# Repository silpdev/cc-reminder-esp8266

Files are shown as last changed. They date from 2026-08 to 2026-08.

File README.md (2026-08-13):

# cc-reminder-esp8266

Đèn báo trạng thái Claude Code, chạy trên Wemos D1 Mini (ESP8266) + WS2812.
Kèm vỏ in 3D tham số hoá.

Port từ [Curlyfuu/cc_reminder](https://github.com/Curlyfuu/cc_reminder) — bản
gốc dùng ESP32-C3 + BLE. ESP8266 không có Bluetooth nên bản này chuyển sang
WiFi/HTTP, và hoá ra lại nhanh hơn: mỗi hook mất ~50ms thay vì 1–3 giây scan BLE.
Đổi lại, đèn cắm nguồn USB ở đâu cũng được, không cần ở gần máy tính.

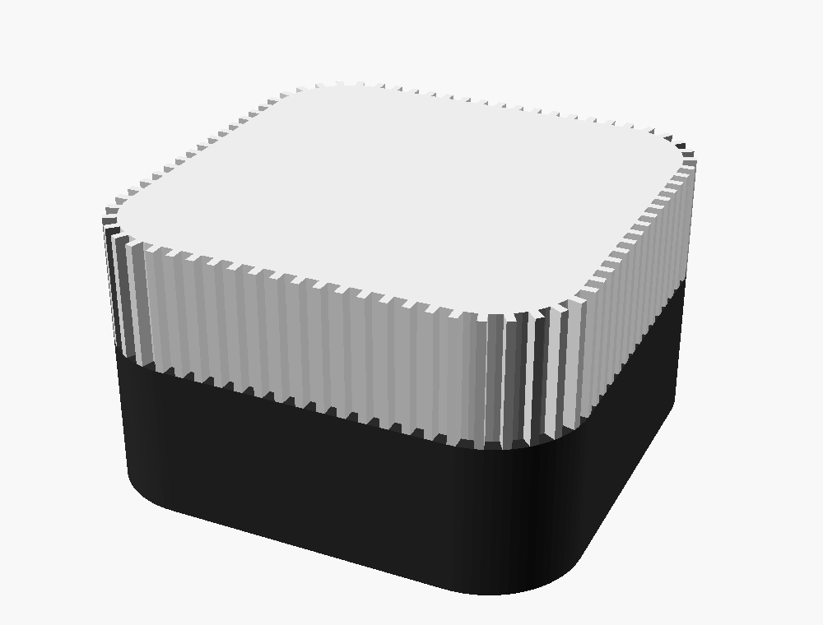
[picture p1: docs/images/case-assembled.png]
Vỏ lắp hoàn chỉnh


| Màu | Trạng thái | Khi nào |
|---|---|---|
| Xanh lá, sáng đứng | `IDLE` | Claude Code rảnh |
| Vàng cam, đập chậm | `WORKING` | đang chạy |
| Đỏ, đập nhanh | `INTERACT` | đang xin xác nhận quyền |

## Phần cứng

| Món | Ghi chú |
|---|---|
| Wemos D1 Mini (ESP8266) | |
| 1 LED WS2812B | cắt ra từ dây strip |
| 3 sợi dây 26–28 AWG | dây nhiều sợi mảnh, đừng dùng dây đơn cứng |

### Đấu nối

| Strip | D1 Mini |
|---|---|
| VCC (5V) | **3V3** |
| DIN | **D9 / RX (GPIO3)** |
| GND | G |

Hai điểm dễ sai:

**GPIO3 là bắt buộc.** Thư viện `NeoPixelBus` chỉ chạy được DMA trên chân này.
Nếu dùng bit-bang (`Adafruit_NeoPixel`) thì WiFi interrupt sẽ cắt ngang làm sai
timing → LED nhảy màu ngẫu nhiên. Đây là lỗi kinh điển của combo
ESP8266 + WS2812 + WiFi.

**Cấp nguồn từ 3V3, không phải 5V.** Ngưỡng HIGH của WS2812 là 0.7 × Vdd. Ở
3.3V thì ngưỡng chỉ ~2.3V, khớp thoải mái với mức GPIO. Nếu cấp 5V thì ngưỡng
lên 3.5V, cao hơn mức GPIO xuất ra — chạy được nhưng không ổn định. Với 1 LED
thì 3V3 dư sức.

Nếu dùng nhiều LED và buộc phải cấp 5V: mắc 1 diode 1N4148 nối tiếp trên dây
nguồn, sụt 0.6V xuống ~4.4V để hạ ngưỡng về ~3.1V.

## Cài đặt

### 1. Test LED trước

```bash
cd test
pio run -t upload && pio device monitor
```

Phải thấy đỏ → xanh lá → xanh dương → trắng. Nếu đỏ và xanh lá đổi chỗ nhau,
sửa `NeoGrbFeature` thành `NeoRgbFeature`.

### 2. Nạp firmware

```bash
cd firmware
pio run -t upload
```

Không cần sửa code — WiFi cấu hình qua trang web, xem mục bên dưới.

Kiểm tra: `curl http://cc-reminder.local/api/status`

### 3. Cấu hình hook Claude Code

Chép `host/settings.example.json` vào `~/.claude/settings.json`, sửa đường dẫn.
Kiểm tra bằng `/hooks` trong Claude Code — menu đó liệt kê mọi hook đang có và
cho biết nó đến từ file settings nào.

| Event | Trạng thái | Tại sao chọn event này |
|---|---|---|
| `SessionStart` | IDLE | đặt lại đèn khi mở session |
| `UserPromptSubmit` | WORKING | bắn ngay khi bạn gửi prompt |
| `Notification` | INTERACT | matcher `permission_prompt\|idle_prompt\|agent_needs_input` |
| `Stop` | IDLE | Claude trả lời xong |
| `SessionEnd` | IDLE | đóng session |

**Vì sao `Notification` mà không phải `PermissionRequest`.** Cả hai đều có thật.
Nhưng `PermissionRequest` bắn mỗi khi có quyết định về quyền, kể cả những lần
được rule tự cho qua mà không hỏi bạn — đèn sẽ nháy đỏ vô ích.
`Notification` với matcher trên chỉ bắn khi Claude **thật sự đang chờ bạn**, và
bắt thêm cả trường hợp đứng chờ mà không phải xin quyền (`idle_prompt`), đúng
là lúc bạn cần đèn báo nhất. Muốn dùng `PermissionRequest` thì cũng được, thêm
song song vào cũng không sao.

**Mọi hook đều `async: true`.** Hook chạy nền, không chặn session. Nếu không có
cờ này, `UserPromptSubmit` sẽ chặn Claude xử lý prompt cho tới khi hook xong —
mà bước dò IP lần đầu có thể mất ~1 giây.

**Dùng exec form (`command` + `args`).** Mỗi phần tử `args` được truyền thành
đúng một tham số, không qua shell, nên đường dẫn có dấu cách cũng không sao.

### Vì sao script luôn exit 0

Đây không phải chi tiết nhỏ. Trong Claude Code, exit code 2 của hook có nghĩa
khác nhau tùy event, và với các event mình dùng thì rất tệ:

| Event | Exit 2 gây ra |
|---|---|
| `UserPromptSubmit` | **chặn prompt và xoá nó khỏi context** |
| `Stop` | **ngăn Claude dừng, bắt nó tiếp tục** |

Nghĩa là một cái đèn LED rút phích có thể làm treo phiên làm việc của bạn.
Script bắt mọi exception và luôn trả về 0, kể cả khi không tìm thấy thiết bị.

### Vì sao script không in ra stdout

Với `UserPromptSubmit`, Claude Code lấy stdout của hook làm **context cho
Claude đọc**. Nên script chỉ in khi bạn gọi tay (`STATUS`, `discover`); lúc đổi
trạng thái nó im lặng hoàn toàn. Muốn xem log thì đặt `CC_REMINDER_DEBUG=1`,
log đi ra stderr.

Tài liệu hook: https://code.claude.com/docs/en/hooks

## Trang web cấu hình

Firmware trong `firmware/` có trang web cấu hình, **không cần sửa code hay nạp
lại để đổi WiFi hoặc màu đèn**. Cấu hình lưu trong EEPROM.

### Lần đầu

1. Nạp firmware, cấp nguồn
2. Đèn **đập xanh dương** = đang ở chế độ AP, chờ cấu hình
3. Kết nối WiFi `cc-reminder-setup` (mở, không mật khẩu)
4. Mở `http://192.168.4.1` — điện thoại thường tự bung trang lên nhờ captive portal
5. Bấm **Quét**, điền tối đa 3 mạng WiFi, bấm **Lưu & khởi động lại**

Sau đó vào `http://cc-reminder.local` (hoặc IP) để cấu hình tiếp.

Nếu không mạng nào trong danh sách khả dụng, thiết bị quay về chế độ AP.

### Cấu hình được gì

| | Ghi chú |
|---|---|
| Độ sáng | 1–255, áp dụng ngay |
| Số LED | 1–24, cần khởi động lại |
| Thứ tự màu | GRB / RGB — sửa lỗi "đỏ ra xanh lá" ngay từ web, khỏi nạp lại |
| Màu từng trạng thái | color picker cho IDLE / WORKING / INTERACT |
| Nhịp đập | bật/tắt và chu kỳ riêng cho từng trạng thái |
| Ambient | thời gian chờ, hiệu ứng, tốc độ, độ sáng riêng, màu |
| 3 mạng WiFi | nhà / công ty / hotspot, cần khởi động lại |
| Hostname | cần khởi động lại |

Có sẵn 3 nút thử IDLE / WORKING / INTERACT để xem màu ngay trên đèn thật, và
nút xoá cấu hình về mặc định.

Mật khẩu WiFi **không bao giờ được gửi về trình duyệt**. Để trống ô mật khẩu
khi lưu thì mật khẩu cũ được giữ nguyên.

### Sửa trang web

HTML nằm ở `firmware/web/page.html`, được nhúng vào PROGMEM trong `main.cpp`.
Sau khi sửa HTML:

```bash
python3 tools/embed_page.py
```

Script chỉ thay phần giữa 2 marker `PAGE BEGIN` / `PAGE END`, không đụng vào
code còn lại. Đừng sửa HTML trực tiếp trong `main.cpp` — lần chạy script sau
sẽ ghi đè.

### API

| Endpoint | |
|---|---|
| `GET /` | trang cấu hình |
| `GET /state?s=IDLE\|WORKING\|INTERACT` | đổi trạng thái (dùng cho hook) |
| `GET /status` | tên trạng thái, dạng text |
| `GET /api/status` | JSON: state, ap, slot, ssid, ip, host, rssi, uptime, heap, fx, fxname, idlefor |
| UDP `:45678` gửi `CCR?` | trả về JSON có IP — dùng để dò thiết bị |
| `GET /api/config` | JSON cấu hình hiện tại (không có mật khẩu) |
| `POST /api/config` | lưu cấu hình, form-urlencoded |
| `GET /api/scan` | quét WiFi |
| `POST /api/preview?fx=N` | xem thử hiệu ứng 15s, không lưu |
| `POST /api/reboot`, `POST /api/reset` | khởi động lại / xoá cấu hình |

`/state` và `/status` giữ nguyên như bản cũ nên `host/cc_reminder_http.py`
không phải sửa gì.

### firmware-minimal

`firmware-minimal/` là bản đơn giản: WiFi hardcode trong `config.h`, không có
trang web. Nhẹ hơn, ít thứ có thể sai hơn. Dùng nếu bạn không cần cấu hình
qua web.

## Ambient — IDLE lâu thì bật hiệu ứng

IDLE quá lâu (mặc định 5 phút) thì đèn chuyển sang hiệu ứng trang trí, và trở
lại ngay khi có hook bắn tới.

**Giới hạn cần biết:** với 1 LED thì mọi hiệu ứng *không gian* — chạy đuổi, sao
băng, cầu vồng trải dọc — đều vô nghĩa. Năm hiệu ứng dưới đây đều là hiệu ứng
*theo thời gian*, chọn để đẹp ở 1 pixel. Engine viết cho N pixel, nên cắt thêm
LED thì Cầu vồng, Lấp lánh và Cực quang tự thành hiệu ứng chạy dọc nhờ độ lệch
pha giữa các pixel.

| Hiệu ứng | Cảm giác | Cách làm |
|---|---|---|
| Nến cháy | lửa thật, không theo chu kỳ | random walk nhân 2 sine lệch tần (6.1 và 13.7 rad/s) |
| Cầu vồng trôi | đổi màu rất chậm | hue tăng đều 0.035/s |
| Nhịp thở | trầm, một màu bạn chọn | cosine, sàn 12% |
| Lấp lánh | đom đóm, ~2.6s một lần lóe | (sin·sin)³ — đỉnh nhọn, phần lớn tối |
| Cực quang | teal ↔ tím dịch chuyển | 2 sine lệch pha điều khiển hue và độ sáng riêng |

Độ sáng ambient có thang riêng, mặc định **28/255** — tối hơn hẳn trạng thái, vì
ambient chạy đúng lúc bạn không nhìn vào nó. Đo trên mô phỏng thì độ chói đỉnh
của cả 5 hiệu ứng đều dưới 26/255.

Nút **Xem thử 15 giây** trên trang cấu hình chạy hiệu ứng ngay trên đèn thật mà
không lưu vào EEPROM, nên thử thoải mái.

Đặt `idle = 0` để tắt hẳn ambient.

### Thêm: làm mịn chuyển màu

Đổi trạng thái giờ không snap nữa. Mỗi frame màu tiến 25% về đích, hằng số thời
gian ~60ms ở 50Hz — đủ xoá cảm giác giật, không đủ để làm chậm nhịp đập của
INTERACT (chu kỳ 900ms). Chỉ áp dụng cho đường một-màu-đồng-nhất; hiệu ứng
ambient vẽ trực tiếp vì phần rung của Nến và Lấp lánh là cố ý.

## Mang đi đâu cũng chạy

Đèn báo trạng thái thì phải nằm cạnh mắt bạn mới có nghĩa, nên nó di chuyển
cùng laptop — nhà, công ty, quán. Firmware xử lý việc này ở hai đầu:

**Thiết bị nhớ 3 mạng WiFi.** Bật nguồn ở đâu, nó quét xem mạng nào trong
danh sách đang có mặt rồi nối vào mạng **mạnh nhất**. Không phải cấu hình lại.
Ba slot đủ cho nhà, công ty, và hotspot điện thoại. Mất WiFi quá 20 giây thì
nó tự quét lại từ đầu — rút ở nhà cắm ở công ty là xong, không cần làm gì.

**Host script tự tìm IP.** IP đổi theo từng mạng nên script dò theo thứ tự,
được bước nào thì cache lại:

| Bước | Khi nào dùng | Thời gian |
|---|---|---|
| 1. Biến `CC_REMINDER_HOST` | khi bạn muốn ép cứng | — |
| 2. Cache từ lần trước | ~99% trường hợp | ~30ms |
| 3. mDNS `cc-reminder.local` | macOS, Linux | ~200ms |
| 4. UDP broadcast `CCR?` :45678 | khi mDNS chết | ~50ms |
| 5. Quét subnet /24 | khi broadcast không qua được | ~1s |

Bước 5 tồn tại vì **WSL2**. Mạng WSL2 là mạng NAT riêng nên broadcast và mDNS
không ra được LAN thật, nhưng kết nối unicast tới IP LAN thì được. Script lấy
subnet LAN từ `ipconfig.exe` rồi quét.

Muốn bỏ hẳn bước 5: Windows 11 + WSL bật mirrored networking. Thêm vào
`C:\Users\<bạn>\.wslconfig`:

```ini
[wsl2]
networkingMode=mirrored
```

Lúc đó broadcast và mDNS chạy bình thường.

Lệnh hữu ích:

```bash
python3 host/cc_reminder_http.py discover   # do lai, in ra IP
python3 host/cc_reminder_http.py forget     # xoa cache
CC_REMINDER_DEBUG=1 python3 host/cc_reminder_http.py IDLE   # xem dung buoc nao
```

### Hai thứ sẽ cắn bạn ở WiFi công ty

**WPA2-Enterprise (802.1X/PEAP).** Nếu WiFi công ty đăng nhập bằng tài khoản
chứ không phải mật khẩu chung, firmware này không nối được — nó dùng
`WiFi.begin(ssid, pass)` thuần. Đường tránh: mạng guest, hoặc hotspot điện thoại.

**Client isolation.** Nhiều mạng công ty và mạng guest chặn máy-nói-với-máy
trong cùng SSID. Khi đó dù cùng LAN, laptop vẫn không gọi được đèn. Thử trước
bằng cách ping điện thoại từ laptop khi cả hai cùng WiFi. Nếu bị chặn thì dùng
hotspot điện thoại — mạng của bạn, không có isolation.

Tôi đã cân nhắc MQTT cho trường hợp này (cả hai bên đều đi ra ngoài nên xuyên
được isolation) nhưng bỏ: broker công cộng đều bắt buộc TLS, mà BearSSL trên
ESP8266 ngốn 16–20KB RAM mỗi handshake, chạy cạnh web server và DMA trên chip
80KB là dễ crash ngẫu nhiên. Hotspot điện thoại giải quyết cùng vấn đề mà
không thêm gì.

## Vỏ in 3D

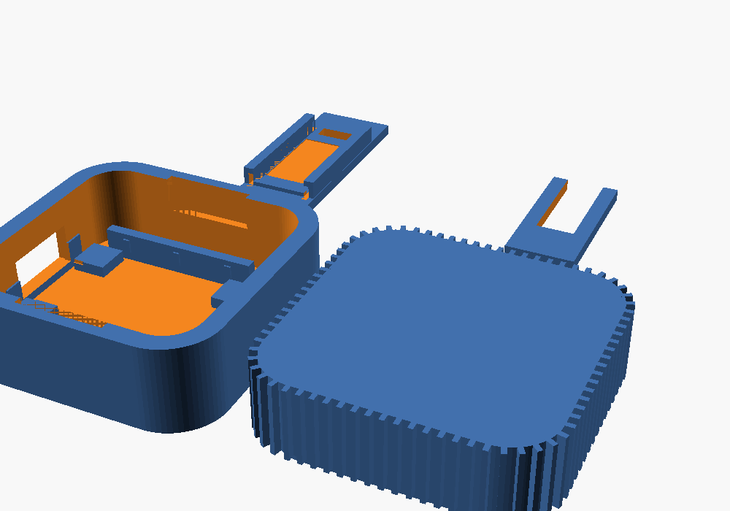
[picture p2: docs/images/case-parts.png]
Các part


STL nằm trong `hardware/stl/`, đã lật sẵn đúng hướng in.

| File | Màu | |
|---|---|---|
| `base.stl` | **đen** | đế. Màu đen quan trọng — chặn sáng loang ra đáy |
| `diffuser.stl` | **trắng** trong/sữa | nắp tán sáng, vành răng lược |
| `led_bar.stl` | đen | thanh đỡ vắt ngang, giữ LED ở giữa |
| `led_clip.stl` | đen | thanh gài, trượt ngang để ép LED |
| `fit_test.stl` | bất kỳ | miếng thử khớp, xem bên dưới |

Tổng thể 46.6 × 46.6 × 27mm, lòng trong 40 × 40mm.

### In `fit_test.stl` trước

Miếng thử 15×34mm, in ~5 phút, gồm đúng phần thành USB + hai đầu hốc board.
Đặt board vào, cắm dây USB, rồi đối chiếu:

| Kết quả | Sửa biến | Cách sửa |
|---|---|---|
| Board chặt quá / không vào | `pcb_fit` | tăng 0.1 mỗi lần |
| Board lỏng, lắc được | `pcb_fit` | giảm về 0.15, hoặc `crush_h` lên 0.5 |
| Lỗ USB lệch cao/thấp | `usb_off_z` | + lên, − xuống |
| Lỗ USB lệch ngang | `usb_off_y` | + là sang +Y |
| Phích không tới cổng | `usb_cb_d` | tăng lên 2.8 |
| Nắp chặt quá / còn lỏng | `lip_nub` | giảm 0.15 / tăng 0.35 |

Chỉ khi miếng thử khớp mới in `base.stl`. Board mỗi lô lệch nhau 0.2–0.3mm nên
bước này gần như luôn cần.

### Thông số in

| | base / led_bar / led_clip | diffuser |
|---|---|---|
| Layer | 0.2mm | 0.2mm |
| Wall loops | 4 | **2** (giữ đúng 0.8mm cho răng lược) |
| Infill | 25% | **0%** |
| Top/bottom | 4 | **5** |
| Support | không | không |

`diffuser` in **úp ngược** — mặt tán sáng áp xuống bàn nên phẳng mịn nhất.
STL đã lật sẵn.

### Sửa thiết kế

Mở `hardware/cc_reminder_case.scad`, các biến đều ở đầu file.

```bash
openscad -D 'part="base"' -o base.stl cc_reminder_case.scad
```

`part` nhận: `base`, `diffuser`, `led_bar`, `led_clip`, `fit_test`, `all`.

### Thứ tự lắp

1. Luồn 3 dây LED qua khe trên `led_bar`
2. Đặt strip vào hốc giữa 2 ray
3. **Trượt** `led_clip` vào từ đầu hở, đẩy tới khi chạm chân chặn
4. Đặt D1 Mini vào đế — gờ bù sai số sẽ hơi cấn, đó là bình thường
5. Nối dây theo bảng ở trên
6. Trượt `led_bar` xuống 2 rãnh ở thành ±Y
7. Ấn nắp vào — 8 nub trên gờ cắm sẽ giữ khít

## Ghi chú kỹ thuật

- **Serial:** DMA chiếm GPIO3 nên Serial chỉ gửi ra được, không nhận vào.
  Serial Monitor vẫn xem log bình thường. Cần RX thì đổi sang
  `NeoEsp8266Uart1800KbpsMethod` (dùng GPIO2).
- **Giới hạn dòng GPIO:** ESP8266 là 12mA/chân, ESP32 là 20mA. Đây là lý do
  bản gốc ESP32 có thể cắm LED rời không cần điện trở mà vẫn chạy, còn ESP8266
  thì không nên. WS2812 tránh được vấn đề này vì có IC hằng dòng tích hợp.
- **Chân cần tránh trên D1 Mini:** D3 (GPIO0) và D8 (GPIO15) quyết định boot
  mode; D0 (GPIO16) không có PWM; D4 (GPIO2) đã có LED onboard và là TX1 lúc boot.

## License

MIT

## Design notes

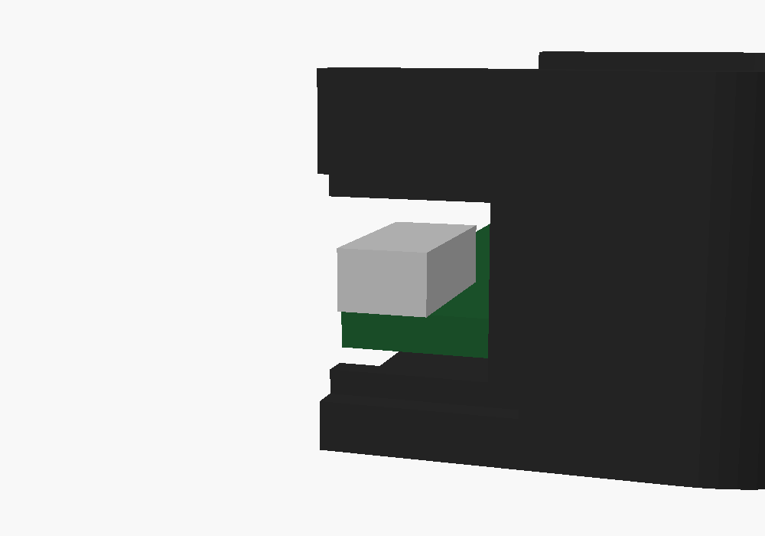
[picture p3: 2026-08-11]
docs/images/usb-section.png

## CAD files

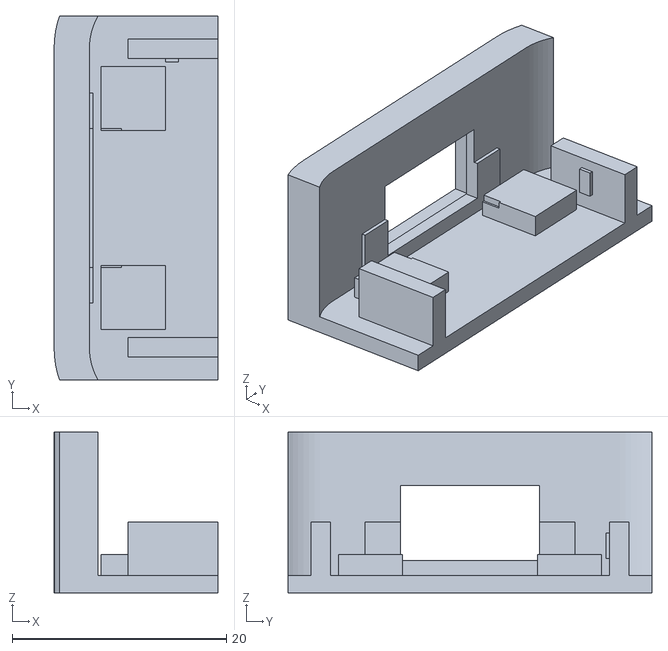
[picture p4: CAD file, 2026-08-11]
hardware/stl/fit_test.stl
15.3 x 34.0 x 15.0

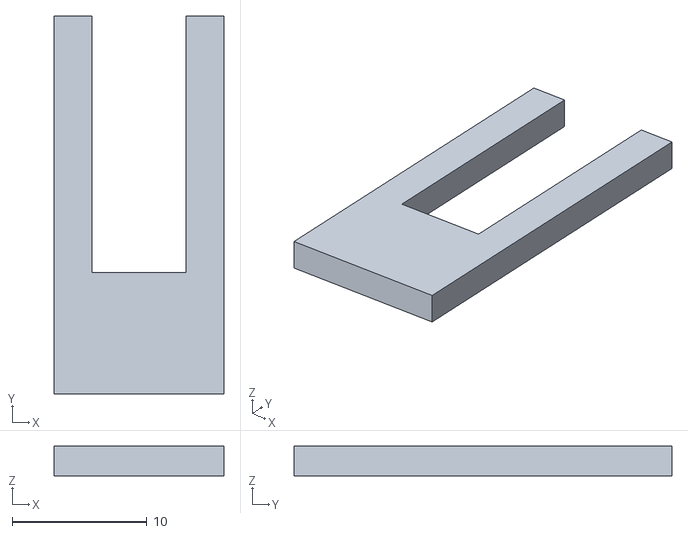
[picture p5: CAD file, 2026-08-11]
hardware/stl/led_clip.stl
12.6 x 28.0 x 2.20

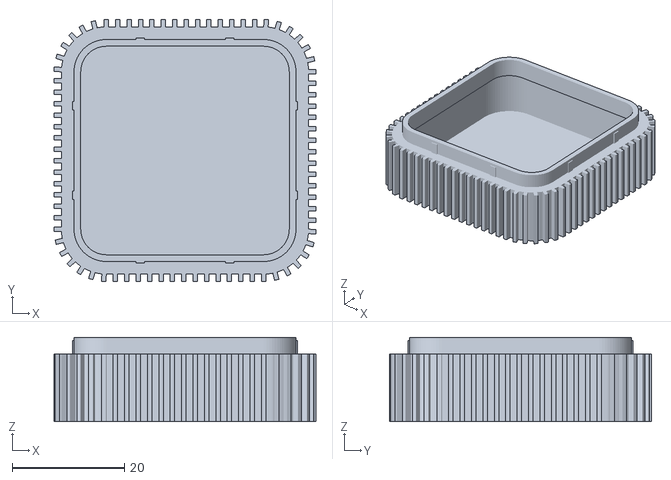
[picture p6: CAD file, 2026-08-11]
hardware/stl/diffuser.stl
46.6 x 46.6 x 15.0

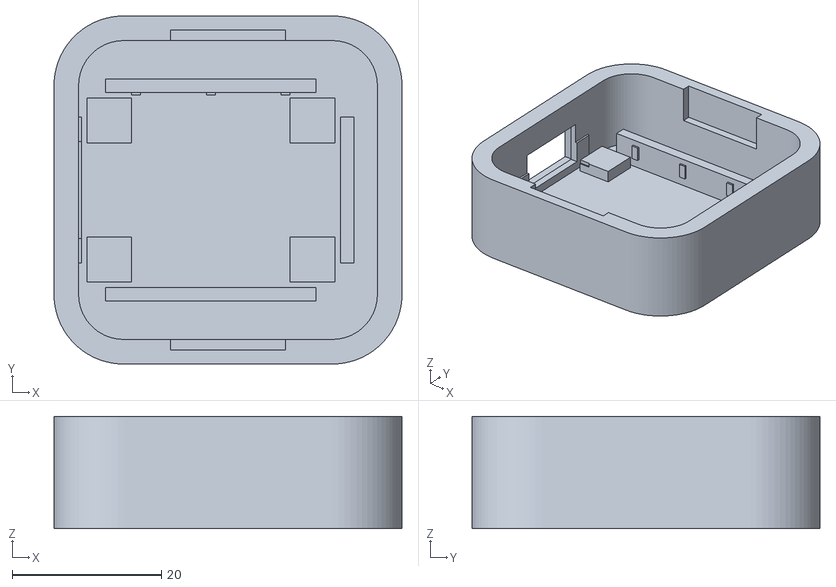
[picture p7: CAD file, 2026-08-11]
hardware/stl/base.stl
46.6 x 46.6 x 15.0

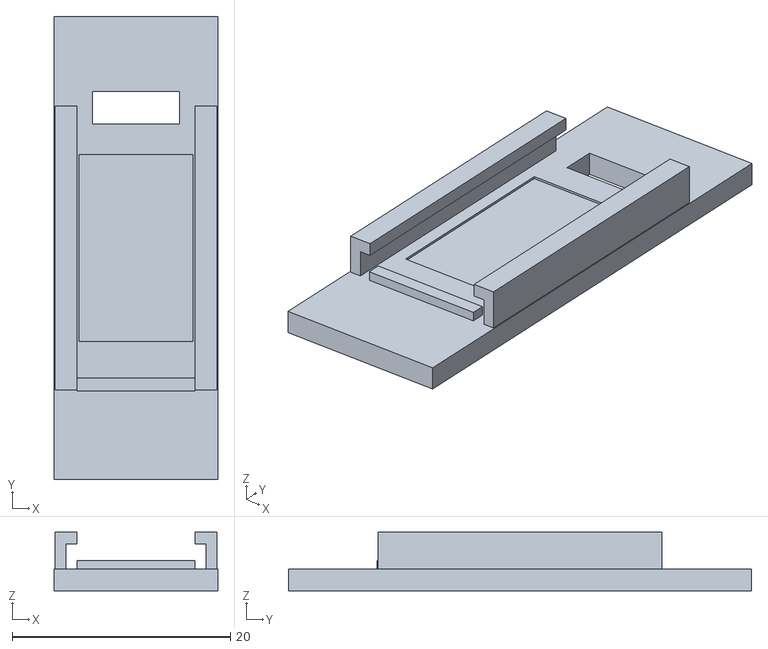
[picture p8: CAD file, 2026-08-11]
hardware/stl/led_bar.stl
15.0 x 42.4 x 5.40

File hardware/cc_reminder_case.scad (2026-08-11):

/* =====================================================================
   cc-reminder case  -  Wemos D1 Mini + 1x WS2812        v3
   ---------------------------------------------------------------------
   THAY DOI SO VOI V1:
   1. Hoc board la HOC KIN (4 thanh bao quanh) thay vi 4 go o goc.
      Khe ho giam tu 0.4 -> 0.25mm/ben, them 3 go bu sai so (crush rib)
      de bu dung sai giua cac lo board.
      Board duoc day sat vao thanh USB -> lo USB khong con lech.
   2. Lo USB tinh tu mat tren PCB, co bien tinh chinh usb_off_y/usb_off_z,
      va co hoc lom mat ngoai de phich cam vao sau hon.
   3. THANH GAI thiet ke lai hoan toan: bo 4 chan mong, doi thanh tam
      hinh chu U truot ngang vao 2 thanh ray. Khong con chi tiet nao
      chiu uon theo huong yeu cua vat in.
   4. Them part "fit_test": mieng thu khop, in ~5 phut de kiem tra hoc
      board + lo USB truoc khi in lai ca de.

   THAY DOI V3:
   5. Mat ngoai cua DE noi ra bang dau vanh rang luoc cua nap
      (44 -> 46.6mm) de hai mat ngoai TRUNG NHAU. Long trong van 40mm,
      nen hoc board va lo USB KHONG doi - da canh roi thi giu nguyen.
      Thanh de day len 2.0 -> 3.3mm; hoc lom USB tang len 2.4mm de bu lai.
   6. Them 8 nub ma sat tren go cam cua nap -> nap khit, khong rung lac.

   openscad -D 'part="base"' -o base.stl cc_reminder_case.scad
   ===================================================================== */

part        = "all";   // [all, base, diffuser, led_bar, led_clip, fit_test]
print_ready = true;    // STL xuat ra da lat san dung huong in

$fn = 72;

/* ---------------- VO ---------------- */
case_w      = 44;
corner_r    = 8;
wall        = 2.0;
floor_t     = 1.6;
base_h      = 15;

/* ---------------- BOARD ---------------- */
pcb_x        = 34.2;   // <-- DO LAI board cua ban
pcb_y        = 25.6;   // <-- DO LAI board cua ban
pcb_t        = 1.6;
pcb_fit      = 0.25;   // khe ho MOI BEN. Chat qua -> tang 0.1
crush_h      = 0.35;   // go bu sai so tren thanh +Y
usb_edge_gap = 0.6;    // khe tu canh PCB den thanh vo phia USB
standoff_h   = 2.0;

/* ---------------- LO USB ----------------
   Tam lo tinh tu MAT TREN PCB cong usb_ctr_dz.
   Micro-USB tren D1 Mini cao ~2.6mm nen tam o khoang 1.3mm.   */
usb_w        = 13.0;
usb_h        = 7.0;
usb_ctr_dz   = 1.3;
usb_off_y    = 0;      // + la dich sang +Y
usb_off_z    = 0;      // + la dich len cao
usb_cb_w     = 16;     // hoc lom mat ngoai cho phich cam sau hon
usb_cb_h     = 9;
usb_cb_d     = 2.4;   // sau hon v2 vi thanh de day len 3.3mm

/* ---------------- LED STRIP ---------------- */
strip_x     = 10.0;
strip_y     = 16.7;    // strip 100 LED/m -> doi thanh 10
strip_gap   = 0.4;
recess_d    = 0.2;

/* ---------------- THANH DO LED ---------------- */
bar_w       = 15.0;
bar_t       = 2.0;
bar_z       = 9.0;
bar_grip    = 1.4;
bar_gap     = 0.4;
wire_sl_x   = 8;
wire_sl_y   = 3;

/* ---------------- RAY + THANH GAI ----------------
   Tam gai truot NGANG vao 2 ray -> chiu luc trong mat phang,
   dung huong khoe nhat cua vat in FDM.                        */
rail_x      = 6.4;     // tam ray
rail_t      = 2.0;
rail_len    = 26;
rail_h      = 3.4;
slot_h      = 2.3;     // chieu cao khe truot
slot_d      = 1.0;     // do sau khe an vao ray
stop_y      = 12.5;    // chan chan cuoi hanh trinh
stop_w      = 1.2;
stop_h      = 0.8;

clip_t      = 2.2;     // day tam gai
clip_len    = 28;
clip_gap    = 0.2;
notch_x     = 7.0;     // be rong khe chu U cho LED loi qua
notch_y0    = -5;

/* ---------------- NAP TAN SANG ---------------- */
dif_h       = 12;
dif_wall    = 1.2;
dif_top     = 1.0;
lip_h       = 3.0;
lip_gap     = 0.25;
lip_nub     = 0.25;    // nub ma sat tren go cam. Chat qua -> giam 0.1
fin_pitch   = 2.0;
fin_w       = 0.8;
fin_len     = 1.3;
crown       = 0;       // 1.5 = giong anh goc, nhung phai bat support

/* ================= DAN XUAT ================= */
S       = case_w/2;              // than vo = mat ngoai thanh nap
Si      = S - wall;              // long trong - GIU NGUYEN 40mm
ri      = corner_r - wall;
// Mat ngoai cua DE noi ra tan dau vanh rang luoc -> trung mat voi nap
S_out   = S + fin_len;
r_out   = corner_r + fin_len;
// Day board sat ve phia thanh USB -> lo USB luon khop
pcb_off_x = -(Si - usb_edge_gap - pcb_x/2);
pcb_top   = floor_t + standoff_h + pcb_t;
usb_z     = pcb_top + usb_ctr_dz + usb_off_z;
bar_top   = bar_t;
clip_w    = 2*(rail_x - rail_t/2 + slot_d) - clip_gap;

/* ================= HELPER ================= */
module rsq(s, r) { offset(r = r) square([2*(s-r), 2*(s-r)], center = true); }
module ring(s, r, t) { difference() { rsq(s, r); rsq(s - t, r - t); } }

/* ================= BASE ================= */

// Hoc kin bao quanh board
module pcb_pocket() {
    px = pcb_x/2 + pcb_fit;
    py = pcb_y/2 + pcb_fit;
    h  = standoff_h + pcb_t + 1.4;
    t  = 1.8;

    // 2 thanh doc canh dai
    for (sy = [-1, 1])
        translate([pcb_off_x, sy*(py + t/2), floor_t + h/2])
            cube([pcb_x - 6, t, h], center = true);
    // 2 thanh 2 dau ngan
    for (sx = [-1, 1])
        translate([pcb_off_x + sx*(px + t/2), 0, floor_t + h/2])
            cube([t, pcb_y - 6, h], center = true);
    // be do PCB
    for (sx = [-1, 1], sy = [-1, 1])
        translate([pcb_off_x + sx*(pcb_x/2 - 3.5), sy*(pcb_y/2 - 3.5),
                   floor_t + standoff_h/2])
            cube([6, 6, standoff_h], center = true);
    // go bu sai so: nen board ve phia -Y cho khit
    for (dx = [-10, 0, 10])
        translate([pcb_off_x + dx, py - crush_h/2 + 0.02,
                   floor_t + standoff_h + pcb_t/2])
            cube([1.2, crush_h, pcb_t + 0.8], center = true);
}

module base_cuts() {
    // lo USB xuyen qua ca thanh vo va thanh hoc board
    translate([-S_out - 3, usb_off_y - usb_w/2, usb_z - usb_h/2])
        cube([(S_out - Si) + 6, usb_w, usb_h]);
    // hoc lom mat ngoai cho phich cam sau hon
    translate([-S_out - 0.1, usb_off_y - usb_cb_w/2, usb_z - usb_cb_h/2])
        cube([usb_cb_d + 0.1, usb_cb_w, usb_cb_h]);
    // 2 ranh cho dau thanh do LED
    for (sy = [-1, 1])
        translate([0, sy*(Si + bar_grip/2), (bar_z + base_h + 1)/2])
            cube([bar_w + bar_gap, bar_grip, base_h + 1 - bar_z], center = true);
    // khe thoat nhiet
    for (i = [-1, 0, 1])
        translate([pcb_off_x + i*7, 0, -1])
            cube([2, 14, floor_t + 2], center = true);
}

module base() {
    difference() {
        union() {
            // vo da khoet rong truoc, roi moi them hoc board,
            // sau do moi khoet lo -> lo USB xuyen duoc ca hoc board
            difference() {
                linear_extrude(base_h) rsq(S_out, r_out);
                translate([0, 0, floor_t]) linear_extrude(base_h) rsq(Si, ri);
            }
            pcb_pocket();
        }
        base_cuts();
    }
}

// Mieng thu khop: chi phan thanh USB + 2 dau hoc board
module fit_test() {
    intersection() {
        base();
        translate([-S_out - 1, -17, -1]) cube([15 + fin_len, 34, base_h + 2]);
    }
}

/* ================= THANH DO LED ================= */
module led_bar() {
    bar_len = 2*Si + 2*bar_grip - bar_gap;
    difference() {
        union() {
            translate([0, 0, bar_t/2])
                cube([bar_w, bar_len, bar_t], center = true);
            // 2 thanh ray dan huong tam gai
            for (sx = [-1, 1])
                translate([sx*rail_x, 0, bar_t + rail_h/2])
                    cube([rail_t, rail_len, rail_h], center = true);
            // chan chan cuoi hanh trinh
            translate([0, -stop_y, bar_t + stop_h/2])
                cube([2*rail_x - rail_t, stop_w, stop_h], center = true);
        }
        // hoc dinh vi strip
        translate([0, 0, bar_t - recess_d/2 + 0.01])
            cube([strip_x + strip_gap, strip_y + strip_gap, recess_d],
                 center = true);
        // khe truot cho tam gai
        for (sx = [-1, 1])
            translate([sx*(rail_x - rail_t/2 + slot_d/2), 0, bar_t + slot_h/2])
                cube([slot_d, rail_len + 2, slot_h], center = true);
        // khe luon day xuong board
        translate([0, strip_y/2 + 4.5, bar_t/2])
            cube([wire_sl_x, wire_sl_y, bar_t + 2], center = true);
    }
}

/* ================= THANH GAI ================= */
module led_clip() {
    difference() {
        translate([0, 0, clip_t/2])
            cube([clip_w, clip_len, clip_t], center = true);
        // khe chu U mo ve dau +Y: truot qua LED khong bi vuong
        ylen = (clip_len/2 + 1) - notch_y0;
        translate([0, notch_y0 + ylen/2, clip_t/2])
            cube([notch_x, ylen, clip_t + 2], center = true);
    }
}
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

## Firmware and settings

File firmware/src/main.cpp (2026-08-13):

/*
 * cc-reminder - ESP8266 (Wemos D1 Mini) + WS2812
 * Ban ROAMING: nho 3 mang WiFi, tu chon mang manh nhat, va tra loi
 * UDP discovery de host tim duoc IP o bat ky mang nao.
 *
 * Cam o nha hay o cong ty deu chay, khong phai cau hinh lai.
 *
 * DAU NOI
 *   strip VCC -> 3V3
 *   strip DIN -> D9 / RX (GPIO3 - bat buoc, DMA chi chay chan nay)
 *   strip GND -> G
 *
 * API
 *   GET  /                    trang cau hinh
 *   GET  /state?s=IDLE|WORKING|INTERACT
 *   GET  /status              ten trang thai, dang text
 *   GET  /api/status          JSON
 *   GET  /api/config          JSON cau hinh (khong co mat khau)
 *   POST /api/config          luu cau hinh
 *   GET  /api/scan            quet WiFi
 *   POST /api/reboot | /api/reset
 *
 * UDP DISCOVERY
 *   Host broadcast "CCR?" toi port 45678 -> thiet bi tra ve JSON co IP.
 *   Nho vay host khong phu thuoc mDNS (mDNS hay chet tren WSL).
 *
 * Sua HTML o firmware/web/page.html roi chay tools/embed_page.py.
 */

#include <Arduino.h>
#include <ESP8266WiFi.h>
#include <ESP8266WebServer.h>
#include <ESP8266mDNS.h>
#include <WiFiUdp.h>
#include <DNSServer.h>
#include <EEPROM.h>
#include <NeoPixelBus.h>

/* ===================== hang so ===================== */
#define MAX_PIXELS    24
#define NET_SLOTS     3
#define CFG_MAGIC     0x43524D35UL     // doi so = xoa cau hinh cu
#define FX_COUNT      6                // so hieu ung (gom ca "tat")
#define PREVIEW_MS    15000UL          // xem thu hieu ung bao lau
#define AP_SSID       "cc-reminder-setup"
#define EEPROM_SIZE   512
#define DISCO_PORT    45678
#define DISCO_PROBE   "CCR?"
#define RECONNECT_MS  20000UL          // mat wifi bao lau thi quet lai

const uint8_t ST_IDLE     = 0;
const uint8_t ST_WORKING   = 1;
const uint8_t ST_INTERACT  = 2;

/* ===================== cau hinh ===================== */
struct Net {
  char ssid[33];
  char pass[65];
};

struct Config {
  uint32_t magic;
  Net      net[NET_SLOTS];
  char     host[24];
  uint8_t  pixels;
  uint8_t  bright;
  uint8_t  order;              // 0 = GRB (mac dinh), 1 = RGB
  uint8_t  col[3][3];
  uint8_t  pulse[3];
  uint16_t period[3];

  /* Ambient: IDLE lau qua thi chuyen sang hieu ung trang tri */
  uint16_t idleAfter;          // giay; 0 = tat han
  uint8_t  effect;             // 0 tat, 1 nen, 2 cau vong, 3 nhip tho,
                               // 4 lap lanh, 5 cuc quang
  uint8_t  fxSpeed;            // 1..10, 5 = binh thuong
  uint8_t  fxBright;           // do sang rieng cho ambient (thuong thap hon)
  uint8_t  fxCol[3];           // mau dung cho hieu ung nhip tho
};

Config cfg;

/* Chan loi im lang: them field vao Config ma quen tang EEPROM_SIZE thi
   EEPROM.put se ghi tran. Bat loi ngay luc bien dich. */
static_assert(sizeof(Config) <= EEPROM_SIZE, "Config lon hon EEPROM_SIZE");

void setDefaults() {
  memset(&cfg, 0, sizeof(cfg));
  cfg.magic = CFG_MAGIC;
  strncpy(cfg.host, "cc-reminder", sizeof(cfg.host) - 1);
  cfg.pixels = 1;
  cfg.bright = 60;
  cfg.order  = 0;

  cfg.col[0][0] = 0;   cfg.col[0][1] = 255; cfg.col[0][2] = 0;   // IDLE
  cfg.pulse[0]  = 0;   cfg.period[0] = 2000;
  cfg.col[1][0] = 255; cfg.col[1][1] = 90;  cfg.col[1][2] = 0;   // WORKING
  cfg.pulse[1]  = 1;   cfg.period[1] = 2400;
  cfg.col[2][0] = 255; cfg.col[2][1] = 0;   cfg.col[2][2] = 0;   // INTERACT
  cfg.pulse[2]  = 1;   cfg.period[2] = 900;

  cfg.idleAfter = 300;         // 5 phut
  cfg.effect    = 1;           // nen
  cfg.fxSpeed   = 5;
  cfg.fxBright  = 28;          // toi hon han trang thai - de tren ban ban dem
  cfg.fxCol[0] = 255; cfg.fxCol[1] = 120; cfg.fxCol[2] = 30;
}

void loadConfig() {
  EEPROM.begin(EEPROM_SIZE);
  EEPROM.get(0, cfg);
  if (cfg.magic != CFG_MAGIC) {
    Serial.println("eeprom trong -> dung mac dinh");
    setDefaults();
    return;
  }
  if (cfg.pixels < 1 || cfg.pixels > MAX_PIXELS) cfg.pixels = 1;
  if (cfg.bright < 1) cfg.bright = 1;
  if (cfg.order > 1)  cfg.order = 0;
  for (uint8_t i = 0; i < 3; i++) {
    if (cfg.period[i] < 200)   cfg.period[i] = 900;
    if (cfg.period[i] > 10000) cfg.period[i] = 10000;
    if (cfg.pulse[i] > 1)      cfg.pulse[i] = 0;
  }
  for (uint8_t i = 0; i < NET_SLOTS; i++) {
    cfg.net[i].ssid[sizeof(cfg.net[i].ssid) - 1] = '\0';
    cfg.net[i].pass[sizeof(cfg.net[i].pass) - 1] = '\0';
  }
  cfg.host[sizeof(cfg.host) - 1] = '\0';
  if (cfg.host[0] == '\0') strncpy(cfg.host, "cc-reminder", sizeof(cfg.host) - 1);
  if (cfg.effect >= FX_COUNT) cfg.effect = 0;
  if (cfg.fxSpeed < 1 || cfg.fxSpeed > 10) cfg.fxSpeed = 5;
  if (cfg.fxBright < 1) cfg.fxBright = 1;
  if (cfg.idleAfter > 86400) cfg.idleAfter = 300;
}

void saveConfig() {
  cfg.magic = CFG_MAGIC;
  EEPROM.put(0, cfg);
  EEPROM.commit();
  Serial.println("eeprom da luu");
}

uint8_t netCount() {
  uint8_t n = 0;
  for (uint8_t i = 0; i < NET_SLOTS; i++) if (cfg.net[i].ssid[0]) n++;
  return n;
}

/* ===================== LED ===================== */
NeoPixelBus<NeoGrbFeature, NeoEsp8266Dma800KbpsMethod> strip(MAX_PIXELS);

uint8_t state = ST_IDLE;
unsigned long stateAt   = 0;      // luc trang thai doi lan cuoi
unsigned long previewTil = 0;     // dang xem thu hieu ung den khi nao
uint8_t previewFx = 0;
bool    fxActive  = false;        // dang chay ambient?

void setPx(uint16_t i, uint8_t r, uint8_t g, uint8_t b) {
  // order == 1 (strip RGB): dao r/g vi feature dang la GRB
  strip.SetPixelColor(i, (cfg.order == 1) ? RgbColor(g, r, b) : RgbColor(r, g, b));
}

void blankRest() {
  for (uint16_t i = cfg.pixels; i < MAX_PIXELS; i++) setPx(i, 0, 0, 0);
}

/* Lam min chuyen mau cho duong "mot mau dong nhat".
   Moi frame tien 25% ve dich -> hang so thoi gian ~60ms o 50Hz.
   Du de xoa cam giac giat khi doi trang thai, khong du de lam cham nhip dap. */
float curR = 0, curG = 0, curB = 0;

void fillPx(uint8_t r, uint8_t g, uint8_t b, bool smooth) {
  if (smooth) {
    curR += (r - curR) * 0.25f;
    curG += (g - curG) * 0.25f;
    curB += (b - curB) * 0.25f;
  } else {
    curR = r; curG = g; curB = b;
  }
  uint8_t rr = (uint8_t)(curR + 0.5f);
  uint8_t gg = (uint8_t)(curG + 0.5f);
  uint8_t bb = (uint8_t)(curB + 0.5f);
  for (uint16_t i = 0; i < cfg.pixels; i++) setPx(i, rr, gg, bb);
  blankRest();
  strip.Show();
}

void writeAll(uint8_t r, uint8_t g, uint8_t b) { fillPx(r, g, b, false); }

float pulseK(uint16_t periodMs, float floorK) {
  if (periodMs < 1) periodMs = 1;
  float deg = (float)(millis() % periodMs) / (float)periodMs * 360.0f;
  float s = 0.5f - 0.5f * cos(deg * PI / 180.0f);
  return floorK + (1.0f - floorK) * s;
}

/* ---------------- hieu ung ambient ----------------
   Tat ca deu la hieu ung THEO THOI GIAN, khong phai theo khong gian, vi
   thiet bi mac dinh chi co 1 LED. Cac tham so i (chi so pixel) chi tao do
   lech pha, nen dat 8-16 LED thi tu nhien thanh hieu ung chay doc.        */

const char* fxName(uint8_t f) {
  switch (f) {
    case 1: return "candle";
    case 2: return "rainbow";
    case 3: return "breathe";
    case 4: return "twinkle";
    case 5: return "aurora";
    default: return "off";
  }
}

void renderEffect(uint8_t fx) {
  float sp = (float)cfg.fxSpeed / 5.0f;             // 5 = binh thuong
  float t  = (float)millis() / 1000.0f * sp;
  float bm = (float)cfg.fxBright / 255.0f;

  // nen: random walk cong 2 sine lech tan -> chay tu nhien, khong theo chu ky
  static float flick = 0.75f;
  if (fx == 1) {
    flick += ((float)random(-45, 46)) / 1000.0f;
    if (flick < 0.35f) flick = 0.35f;
    if (flick > 1.0f)  flick = 1.0f;
  }

  for (uint16_t i = 0; i < cfg.pixels; i++) {
    float ph = (float)i * 0.55f;                   // do lech pha giua cac pixel
    float h = 0, sat = 1.0f, v = 0;

    switch (fx) {
      case 1: {                                    // nen
        float w = 0.62f + 0.22f * sin(t * 6.1f + ph)
                        + 0.16f * sin(t * 13.7f + ph);
        v = bm * flick * (0.55f + 0.45f * w);
        h = 0.055f + 0.02f * w;                    // cam am, hoi dao quanh
        sat = 0.92f;
        break;
      }
      case 2: {                                    // cau vong troi
        h = t * 0.035f + (float)i / (float)cfg.pixels * 0.6f;
        h = h - floor(h);
        v = bm;
        break;
      }
      case 3: {                                    // nhip tho theo mau fxCol
        float k = 0.12f + 0.88f * (0.5f - 0.5f * cos(t * 0.9f + ph));
        uint8_t r = (uint8_t)(cfg.fxCol[0] * bm * k);
        uint8_t g = (uint8_t)(cfg.fxCol[1] * bm * k);
        uint8_t b = (uint8_t)(cfg.fxCol[2] * bm * k);
        setPx(i, r, g, b);
        continue;
      }
      case 4: {                                    // lap lanh
        float a  = sin(t * 1.7f  + ph * 3.1f);
        float b2 = sin(t * 2.63f + ph * 1.7f);
        float k = a * b2;
        k = (k > 0) ? k * k * k : 0;                // dinh nhon, phan lon la toi
        v = bm * (0.06f + 0.94f * k);
        h = 0.13f; sat = 0.25f;                     // trang am
        break;
      }
      case 5: {                                    // cuc quang
        h = 0.44f + 0.24f * sin(t * 0.31f + ph);
        v = bm * (0.35f + 0.65f * (0.5f + 0.5f * sin(t * 0.47f + ph * 1.3f)));
        sat = 0.85f;
        break;
      }
      default:
        setPx(i, 0, 0, 0);
        continue;
    }

    if (v < 0) v = 0;
    if (v > 1) v = 1;
    RgbColor c = RgbColor(HsbColor(h, sat, v));
    setPx(i, c.R, c.G, c.B);
  }
  blankRest();
  strip.Show();
  curR = curG = curB = 0;      // reset smoothing de khong keo mau cu vao
}

void renderLed() {
  static unsigned long last = 0;
  if (millis() - last < 20) return;                // ~50Hz
  last = millis();

  // xem thu tu trang cau hinh
  if (previewTil && millis() < previewTil) {
    fxActive = true;
    renderEffect(previewFx);
    return;
  }
  if (previewTil && millis() >= previewTil) {
    previewTil = 0;
    stateAt = millis();                            // dem lai tu dau
  }

  // IDLE lau qua -> ambient
  bool wantFx = cfg.effect != 0 && cfg.idleAfter > 0 && state == ST_IDLE &&
                (millis() - stateAt) > (unsigned long)cfg.idleAfter * 1000UL;
  fxActive = wantFx;
  if (wantFx) { renderEffect(cfg.effect); return; }

  uint8_t s = state;
  float k = 1.0f;
  if (cfg.pulse[s]) k = pulseK(cfg.period[s], (s == ST_INTERACT) ? 0.15f : 0.40f);

  float bk = ((float)cfg.bright / 255.0f) * k;
  fillPx((uint8_t)(cfg.col[s][0] * bk),
         (uint8_t)(cfg.col[s][1] * bk),
         (uint8_t)(cfg.col[s][2] * bk), true);
}

/* ===================== web / udp ===================== */
ESP8266WebServer server(80);
DNSServer  dns;
WiFiUDP    disco;
bool apMode = false;
int  activeSlot = -1;

extern const char PAGE_HTML[] PROGMEM;

const char* stateName(uint8_t s) {
  if (s == ST_WORKING)  return "WORKING";
  if (s == ST_INTERACT) return "INTERACT";
  return "IDLE";
}

String jstr(const String& in) {
  String o = in;
  o.replace("\\", "\\\\");
  o.replace("\"", "\\\"");
  return o;
}

String hex3(const uint8_t* c) {
  char b[10];
  snprintf(b, sizeof(b), "#%02x%02x%02x", c[0], c[1], c[2]);
  return String(b);
}

bool parseHex3(const String& s, uint8_t* out) {
  if (s.length() < 7 || s.charAt(0) != '#') return false;
  for (uint8_t i = 0; i < 3; i++) {
    out[i] = (uint8_t)strtol(s.substring(1 + i * 2, 3 + i * 2).c_str(), NULL, 16);
  }
  return true;
}

/* ---- UDP discovery ---- */
void discoBegin() {
  disco.begin(DISCO_PORT);
  Serial.printf("udp discovery: port %d\n", DISCO_PORT);
}

void discoLoop() {
  int sz = disco.parsePacket();
  if (sz <= 0) return;

  char buf[32];
  int n = disco.read(buf, sizeof(buf) - 1);
  if (n < 0) n = 0;
  buf[n] = '\0';

  if (strncmp(buf, DISCO_PROBE, strlen(DISCO_PROBE)) != 0) return;

  String o = "{\"cc-reminder\":1,\"host\":\"";
  o += jstr(String(cfg.host));
  o += "\",\"ip\":\"";   o += WiFi.localIP().toString();
  o += "\",\"port\":80,\"state\":\""; o += stateName(state);
  o += "\"}";

  disco.beginPacket(disco.remoteIP(), disco.remotePort());
  disco.write((const uint8_t*)o.c_str(), o.length());
  disco.endPacket();
}

/* ---- handlers ---- */
void handleRoot() {
  server.send_P(200, "text/html", PAGE_HTML);
}

void handleApiStatus() {
  String o = "{";
  o += "\"state\":\"";  o += stateName(state); o += "\",";
  o += "\"ap\":";       o += (apMode ? "true" : "false"); o += ",";
  o += "\"slot\":";     o += activeSlot;       o += ",";
  o += "\"ssid\":\"";   o += jstr(WiFi.SSID()); o += "\",";
  o += "\"ip\":\"";     o += (apMode ? WiFi.softAPIP().toString()
                                     : WiFi.localIP().toString()); o += "\",";
  o += "\"host\":\"";   o += jstr(String(cfg.host)); o += "\",";
  o += "\"rssi\":";     o += WiFi.RSSI();      o += ",";
  o += "\"uptime\":";   o += (millis() / 1000); o += ",";
  o += "\"heap\":";     o += ESP.getFreeHeap();     o += ",";
  o += "\"fx\":";       o += (fxActive ? "true" : "false"); o += ",";
  o += "\"fxname\":\""; o += fxName(previewTil ? previewFx : cfg.effect);
  o += "\",";
  o += "\"idlefor\":";  o += ((millis() - stateAt) / 1000);
  o += "}";
  server.send(200, "application/json", o);
}
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
void loop() {
  server.handleClient();

  if (apMode) {
    dns.processNextRequest();
    static unsigned long t = 0;
    if (millis() - t > 20) {
      t = millis();
      writeAll(0, 0, (uint8_t)(60 * pulseK(1600, 0.10f)));
    }
    return;
  }

  MDNS.update();
  discoLoop();
  renderLed();

  /* Mat WiFi qua lau -> quet lai tu dau. Day la co che cho phep
     rut o nha cam o cong ty ma khong phai lam gi.               */
  static unsigned long lostAt = 0;
  if (WiFi.status() != WL_CONNECTED) {
    if (lostAt == 0) {
      lostAt = millis();
      Serial.println("mat wifi");
    } else if (millis() - lostAt > RECONNECT_MS) {
      Serial.println("quet lai cac mang da luu");
      lostAt = 0;
      if (!connectBest()) startAP();
    }
  } else {
    lostAt = 0;
  }
}

/* ===================== trang web =====================
   Phan duoi day do tools/embed_page.py sinh ra tu firmware/web/page.html.
   SUA HTML O FILE DO roi chay: python3 tools/embed_page.py
   Dung sua truc tiep trong day - se bi ghi de.                          */
/* ---8<--- PAGE BEGIN --- */
const char PAGE_HTML[] PROGMEM = R"CCR(
<!doctype html>
<html lang="vi"><head>
<meta charset="utf-8">
<meta name="viewport" content="width=device-width,initial-scale=1">
<title>cc-reminder</title>
<style>
:root{--bg:#15171c;--card:#1e2128;--line:#2c313b;--tx:#e6e8ec;--dim:#8b93a1;--ac:#4a9eff}
*{box-sizing:border-box}
body{margin:0;padding:16px;background:var(--bg);color:var(--tx);
font:15px/1.5 -apple-system,BlinkMacSystemFont,"Segoe UI",Roboto,sans-serif;
max-width:520px;margin:0 auto}
h1{font-size:19px;margin:8px 0 4px}
h1 span{color:var(--dim);font-weight:400;font-size:14px}
h2{font-size:14px;text-transform:uppercase;letter-spacing:.06em;color:var(--dim);
margin:0 0 12px}
.card{background:var(--card);border:1px solid var(--line);border-radius:10px;
padding:14px;margin:12px 0}
.row{display:flex;align-items:center;gap:10px;margin:10px 0}
.row label{flex:1;min-width:0}
input,select{background:#12141a;color:var(--tx);border:1px solid var(--line);
border-radius:7px;padding:8px 10px;font-size:15px;font-family:inherit}
input[type=text],input[type=password]{width:100%}
input[type=number]{width:78px}
input[type=color]{width:46px;height:34px;padding:2px;cursor:pointer}
input[type=range]{flex:2;accent-color:var(--ac)}
input[type=checkbox]{width:18px;height:18px;accent-color:var(--ac)}
button{background:#2a2f39;color:var(--tx);border:1px solid var(--line);
border-radius:7px;padding:9px 14px;font-size:14px;font-family:inherit;
cursor:pointer}
button:active{transform:translateY(1px)}
button.pri{background:var(--ac);border-color:var(--ac);color:#08111d;font-weight:600}
button.dgr{color:#ff8080}
.btns{display:flex;gap:8px;flex-wrap:wrap}
.st{display:grid;grid-template-columns:auto 1fr;gap:4px 14px;font-size:14px}
.st b{color:var(--dim);font-weight:400}
.mono{font-variant-numeric:tabular-nums}
.dot{width:10px;height:10px;border-radius:50%;display:inline-block;
margin-right:6px;vertical-align:middle}
.hint{color:var(--dim);font-size:13px;margin-top:8px}
#msg{position:fixed;left:0;right:0;bottom:0;padding:12px;text-align:center;
background:var(--ac);color:#08111d;font-weight:600;transform:translateY(100%);
transition:transform .2s}
#msg.on{transform:none}
</style></head><body>
<h1>cc-reminder <span id="hn"></span></h1>
<div class="card">
<h2>Trạng thái</h2>
<div class="st">
<b>Đèn</b><span id="s-state">—</span>
<b>WiFi</b><span id="s-wifi">—</span>
<b>IP</b><span id="s-ip" class="mono">—</span>
<b>Tín hiệu</b><span id="s-rssi" class="mono">—</span>
<b>Uptime</b><span id="s-up" class="mono">—</span>
<b>Ambient</b><span id="s-fx">—</span>
</div>
</div>
<div class="card">
<h2>Thử đèn</h2>
<div class="btns">
<button onclick="setState('IDLE')">IDLE</button>
<button onclick="setState('WORKING')">WORKING</button>
<button onclick="setState('INTERACT')">INTERACT</button>
</div>
<div class="hint">Bấm để xem màu ngay trên đèn thật.</div>
</div>
<div class="card">
<h2>LED</h2>
<div class="row">
<label for="bright">Độ sáng <span id="bv" class="mono"></span></label>
<input type="range" id="bright" min="1" max="255">
</div>
<div class="row">
<label for="pixels">Số LED</label>
<input type="number" id="pixels" min="1" max="24">
</div>
<div class="row">
<label for="order">Thứ tự màu</label>
<select id="order">
<option value="0">GRB — mặc định</option>
<option value="1">RGB — nếu đỏ ra xanh lá</option>
</select>
</div>
<div id="states"></div>
<div class="hint">Bỏ tick “nhịp” để đèn sáng đứng. Chu kỳ tính bằng ms.</div>
</div>
<div class="card">
<h2>Ambient</h2>
<div class="row">
<label for="idle">Chạy hiệu ứng sau khi IDLE (giây, 0 = tắt)</label>
<input type="number" id="idle" min="0" max="86400" step="30">
</div>
<div class="row">
<label for="fx">Hiệu ứng</label>
<select id="fx">
<option value="0">Tắt</option>
<option value="1">Nến cháy</option>
<option value="2">Cầu vồng trôi</option>
<option value="3">Nhịp thở</option>
<option value="4">Lấp lánh</option>
<option value="5">Cực quang</option>
</select>
</div>
<div class="row">
<label for="fxb">Độ sáng <span id="fxbv" class="mono"></span></label>
<input type="range" id="fxb" min="1" max="255">
</div>
<div class="row">
<label for="fxs">Tốc độ <span id="fxsv" class="mono"></span></label>
<input type="range" id="fxs" min="1" max="10">
</div>
<div class="row">
<label for="fxc">Màu (dùng cho Nhịp thở)</label>
<input type="color" id="fxc">
</div>
<div class="btns"><button onclick="preview()">Xem thử 15 giây</button></div>
<div class="hint">Chỉ có 1 LED nên đây đều là hiệu ứng theo thời gian. Cắt
thêm LED thì Cầu vồng, Lấp lánh và Cực quang tự thành hiệu ứng chạy dọc.
Độ sáng để thấp hơn hẳn trạng thái vì ambient chạy lúc bạn không nhìn.</div>
</div>
<div class="card">
<h2>WiFi</h2>
<div class="row">
<label>Nhớ tối đa 3 mạng — nhà, công ty, hotspot</label>
<button onclick="scan()" id="btn-scan">Quét</button>
</div>
<datalist id="nets"></datalist>
<div id="wifis"></div>
<div class="row"><label for="host">Hostname</label></div>
<div class="row"><input type="text" id="host" autocomplete="off"></div>
<div class="hint">Bật nguồn ở đâu, thiết bị tự quét và chọn mạng có tín hiệu
mạnh nhất trong danh sách. Xoá trống ô SSID để bỏ mạng đó.</div>
</div>
<div class="card">
<div class="btns">
<button class="pri" onclick="save(0)">Lưu</button>
<button onclick="save(1)">Lưu &amp; khởi động lại</button>
<button class="dgr" onclick="factoryReset()">Xoá cấu hình</button>
</div>
</div>
<div id="msg"></div>
<script>
var NAMES = ['IDLE', 'WORKING', 'INTERACT'];
function el(id) { return document.getElementById(id); }
function toast(t) {
var m = el('msg');
m.textContent = t;
m.classList.add('on');
setTimeout(function () { m.classList.remove('on'); }, 2200);
}
function buildWifis() {
var h = '';
for (var i = 0; i < 3; i++) {
h += '<div class="row"><label for="ssid' + i + '" style="flex:0 0 58px">#' +
(i + 1) + '</label>' +
'<input type="text" id="ssid' + i + '" list="nets" autocomplete="off" ' +
'placeholder="SSID"></div>' +
'<div class="row"><label style="flex:0 0 58px"></label>' +
'<input type="password" id="pass' + i + '" ' +
'placeholder="mật khẩu"></div>';
}
el('wifis').innerHTML = h;
}
function buildStates() {
var h = '';
for (var i = 0; i < 3; i++) {
h += '<div class="row">' +
'<label for="c' + i + '">' + NAMES[i] + '</label>' +
'<input type="color" id="c' + i + '">' +
'<label for="p' + i + '" style="flex:0 0 auto">nhịp</label>' +
'<input type="checkbox" id="p' + i + '">' +
'<input type="number" id="t' + i + '" min="200" max="10000" step="100">' +
'</div>';
}
el('states').innerHTML = h;
}
function loadConfig() {
fetch('/api/config').then(function (r) { return r.json(); }).then(function (c) {
for (var k = 0; k < 3; k++) {
el('ssid' + k).value = c.nets[k].ssid;
el('pass' + k).placeholder = c.nets[k].saved ? 'đã lưu — để trống là giữ nguyên'
: 'mật khẩu';
}
el('host').value   = c.host;
el('pixels').value = c.pixels;
el('bright').value = c.bright;
el('bv').textContent = c.bright;
el('order').value  = c.order;
for (var i = 0; i < 3; i++) {
el('c' + i).value   = c.col[i];
el('p' + i).checked = c.pulse[i] === 1;
el('t' + i).value   = c.period[i];
}
el('idle').value = c.idle;
el('fx').value   = c.fx;
el('fxb').value  = c.fxb;
el('fxs').value  = c.fxs;
el('fxc').value  = c.fxc;
el('fxbv').textContent = c.fxb;
el('fxsv').textContent = c.fxs;
}).catch(function () { toast('Không đọc được cấu hình'); });
}
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

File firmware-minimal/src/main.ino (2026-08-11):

/*
 * cc-reminder - ESP8266 (Wemos D1 Mini) + WS2812
 *
 * Den bao trang thai Claude Code. Port tu Curlyfuu/cc_reminder
 * (ban goc dung ESP32-C3 + BLE). ESP8266 khong co Bluetooth nen ban nay
 * dung WiFi/HTTP - nhanh hon: ~50ms moi hook thay vi 1-3s scan BLE.
 *
 * DAU NOI
 *   strip VCC -> 3V3     (1 LED thi 3V3 khop muc logic, khong can diode)
 *   strip DIN -> D9 / RX (GPIO3 - bat buoc, DMA chi chay chan nay)
 *   strip GND -> G
 *
 * API
 *   GET /                       -> trang trang thai dang text
 *   GET /state?s=IDLE|WORKING|INTERACT
 *   GET /status                 -> ten trang thai hien tai
 *
 * SERIAL: DMA chiem GPIO3 nen Serial chi GUI ra duoc, khong nhan vao.
 * Serial Monitor van xem log binh thuong.
 *
 * Copy src/config.h.example -> src/config.h roi dien WiFi truoc khi build.
 */

#include <Arduino.h>
#include <ESP8266WiFi.h>
#include <ESP8266WebServer.h>
#include <ESP8266mDNS.h>
#include <NeoPixelBus.h>

#include "config.h"

/* ---------------- trang thai ---------------- */
const uint8_t ST_IDLE     = 0;
const uint8_t ST_WORKING  = 1;
const uint8_t ST_INTERACT = 2;

uint8_t state = ST_IDLE;

const char* stateName(uint8_t s) {
  if (s == ST_WORKING)  return "WORKING";
  if (s == ST_INTERACT) return "INTERACT";
  return "IDLE";
}

/* ---------------- LED ---------------- */
// Neu goi do ma ra xanh la -> doi NeoGrbFeature thanh NeoRgbFeature
NeoPixelBus<NeoGrbFeature, NeoEsp8266Dma800KbpsMethod> strip(PIXEL_COUNT);

ESP8266WebServer server(80);

void fill(uint8_t r, uint8_t g, uint8_t b) {
  for (uint16_t i = 0; i < PIXEL_COUNT; i++) {
    strip.SetPixelColor(i, RgbColor(r, g, b));
  }
  strip.Show();
}

// Nhip dap: tra ve he so 0..1 theo chu ky
float breathe(uint16_t periodMs, float floorK) {
  float ph = (millis() % periodMs) / (float)periodMs * 360.0f;
  float s  = 0.5f - 0.5f * cos(ph * PI / 180.0f);
  return floorK + (1.0f - floorK) * s;
}

void renderLed() {
  static unsigned long last = 0;
  if (millis() - last < 20) return;   // ~50Hz, du muot va nhe cho CPU
  last = millis();

  float k = 1.0f;
  uint8_t r = 0, g = 0, b = 0;

  if (state == ST_INTERACT) {
    // do, dap nhanh - de nhan ra bang khoe mat
    k = breathe(900, 0.15f);
    r = COL_INTERACT_R; g = COL_INTERACT_G; b = COL_INTERACT_B;
  } else if (state == ST_WORKING) {
    // vang cam, dap cham
    k = breathe(2400, 0.40f);
    r = COL_WORKING_R; g = COL_WORKING_G; b = COL_WORKING_B;
  } else {
    // xanh la, sang dung
    r = COL_IDLE_R; g = COL_IDLE_G; b = COL_IDLE_B;
  }

  float bk = (BRIGHT / 255.0f) * k;
  fill((uint8_t)(r * bk), (uint8_t)(g * bk), (uint8_t)(b * bk));
}

/* ---------------- HTTP ---------------- */
void handleState() {
  String s = server.arg("s");
  s.toUpperCase();

  if      (s == "IDLE")     state = ST_IDLE;
  else if (s == "WORKING")  state = ST_WORKING;
  else if (s == "INTERACT") state = ST_INTERACT;
  else { server.send(400, "text/plain", "BAD_STATE\n"); return; }

  Serial.printf("-> %s\n", stateName(state));
  server.send(200, "text/plain", String("OK ") + stateName(state) + "\n");
}

void handleStatus() {
  server.send(200, "text/plain", String(stateName(state)) + "\n");
}

void handleRoot() {
  String o = "cc-reminder\n";
  o += "state    : "; o += stateName(state); o += "\n";
  o += "ip       : "; o += WiFi.localIP().toString(); o += "\n";
  o += "rssi     : "; o += WiFi.RSSI(); o += " dBm\n";
  o += "uptime   : "; o += (millis() / 1000); o += " s\n";
  o += "pixels   : "; o += PIXEL_COUNT; o += "\n";
  o += "\nGET /state?s=IDLE|WORKING|INTERACT\n";
  server.send(200, "text/plain", o);
}

/* ---------------- setup / loop ---------------- */
void setup() {
  Serial.begin(115200);
  delay(200);
  Serial.println("\n=== cc-reminder (ESP8266 + WS2812) ===");

  strip.Begin();
  // xanh duong mo trong luc cho WiFi
  fill(0, 0, 40);

  WiFi.mode(WIFI_STA);
  WiFi.hostname(HOSTNAME);
  WiFi.setAutoReconnect(true);
  WiFi.persistent(true);
  WiFi.begin(WIFI_SSID, WIFI_PASS);

  Serial.print("wifi");
  uint16_t tries = 0;
  while (WiFi.status() != WL_CONNECTED && tries < 120) {
    delay(250);
    Serial.print(".");
    tries++;
  }
  Serial.println();

  if (WiFi.status() == WL_CONNECTED) {
    Serial.print("ip: ");
    Serial.println(WiFi.localIP());
    if (MDNS.begin(HOSTNAME)) {
      MDNS.addService("http", "tcp", 80);
      Serial.printf("mdns: http://%s.local/\n", HOSTNAME);
    }
  } else {
    // khong noi duoc thi nhay do de biet, van chay tiep de tu reconnect
    Serial.println("wifi FAIL - se tu thu lai");
    for (uint8_t i = 0; i < 6; i++) {
      fill(60, 0, 0); delay(150);
      fill(0, 0, 0);  delay(150);
    }
  }

  server.on("/",       handleRoot);
  server.on("/state",  handleState);
  server.on("/status", handleStatus);
  server.onNotFound([]() { server.send(404, "text/plain", "NOT_FOUND\n"); });
  server.begin();

  state = ST_IDLE;
}

void loop() {
  server.handleClient();
  MDNS.update();
  renderLed();
}

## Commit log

2026-08-11 cc-reminder for ESP8266: WiFi/HTTP firmware + parametric 3D case
    Port of Curlyfuu/cc_reminder from ESP32-C3/BLE to Wemos D1 Mini (ESP8266).
    ESP8266 has no Bluetooth, so state changes arrive over HTTP instead of BLE
    (~50ms per hook vs 1-3s BLE scan).
    Firmware:
    - NeoPixelBus DMA on GPIO3 (bit-bang glitches when WiFi interrupts fire)
    - WS2812 powered from 3V3 so the logic threshold matches the GPIO level
    - states: IDLE solid green, WORKING slow pulse amber, INTERACT fast pulse red
    - WiFi credentials in gitignored config.h
    Case (OpenSCAD, 46.6 x 46.6 x 27mm):
    - base, finned diffuser, LED support bar, slide-in retainer clip
    - fit_test coupon prints in ~5min to dial in board pocket and USB openi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
    [base.stl, cc_reminder_case.scad, diffuser.stl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]
2026-08-11 Add web config: WiFi provisioning AP + LED settings page
    No more reflashing to change WiFi or colours. Settings persist in EEPROM.
    - Falls back to an open AP "cc-reminder-setup" with a captive portal when it
    cannot join the stored network; LED pulses blue to signal setup mode
    - Config page covers brightness, pixel count, per-state colour, pulse on/off
    and period, plus a GRB/RGB toggle so the swapped-red-and-green case is fixed
    from the browser instead of a reflash
    - WiFi password is never sent to the browser; blank field keeps the old one
    - /state and /status kept byte-identical so host/cc_reminder_http.py is untouched
    - HTML lives in firmware/web/page.html and is embedded into PROGME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
    [main.cpp, main.ino]
2026-08-11 Roaming: 3 stored WiFi networks + multi-stage device discovery
    The device travels with the laptop, so it has to work on whatever network it
    is plugged into.
    - stores 3 networks, scans on boot and joins the strongest one present
    - rescans from scratch after 20s without a link, so unplugging at home and
    plugging in at the office needs no interaction
    - answers a UDP "CCR?" probe on :45678 with its own IP
    Host script resolves in stages and caches the winner: env override, cache,
    mDNS, UDP broadcast, /24 unicast scan. The scan stage exists for WSL2, whose
    NAT'd network drops broadcast and mDNS but passes unicast to LAN IPs; the LAN
    subnet is read from ipconfig.exe. README documents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
    [main.cpp]
2026-08-11 Fix hook config against the Claude Code hooks reference
    Checked host/settings.example.json against https://code.claude.com/docs/en/hooks
    and found one real bug plus two things left on the table.
    Bug: Claude Code feeds a UserPromptSubmit hook's stdout into Claude's context.
    The script printed "OK WORKING" there, so that line was injected on every
    prompt. State changes are now silent; only manual invocations (STATUS,
    discover) print, and log output goes to stderr behind CC_REMINDER_DEBUG.
    Missed: async:true runs hooks in the background instead of blocking the session
    while the first discovery pass runs. All five hooks now set it. Switched to exec
    form (command + args) so paths with spaces ne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
2026-08-13 Add ambient idle effects and smooth color transitions
    Five time-based effects (candle, rainbow, breathing, sparkle, aurora)
    kick in after prolonged IDLE, plus a 15s live preview endpoint and
    frame-based color easing so state changes no longer snap.
    [main.cpp]
